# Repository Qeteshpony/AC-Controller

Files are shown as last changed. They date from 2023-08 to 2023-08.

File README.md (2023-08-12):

# Qeteshs AC-Controller



3D Render

[Hardware Documentation](https://qeteshpony.github.io/AC-Controller)

Simple controller for IoT devices with ESP-Home and Home Assistant in mind. This project was mainly started to get better control for our AC system but I guess it can be adapted for about anything. 

The system is based on an ESP32 module, a small LCD and two rotary encoders with optional support for charging and using a LiPo battery. 

The hardware was designed for production by JLCPCB and as many parts as possible were selected from their basic parts library to keep costs low. 

The PCB has two positions for a USB-C port, both are wired in parallel so only one should be soldered in - which one depends on the usecase. 

The display I use is the `DEM 16226 SYH-LY` which is smaller than most 16x2 character displays and available from several retailers. The board most likely needs major changes to be used with another display since the connector is in a different position to most.

I also got shorter 2.54mm headers that only raise the display by about 8mm from the main board so everything is more compact.

The battery used is a 2500 mAH LiPo cell called `LP-785060` with built in protection circuit and about the same measurements as the board so it fits neatly underneath it.

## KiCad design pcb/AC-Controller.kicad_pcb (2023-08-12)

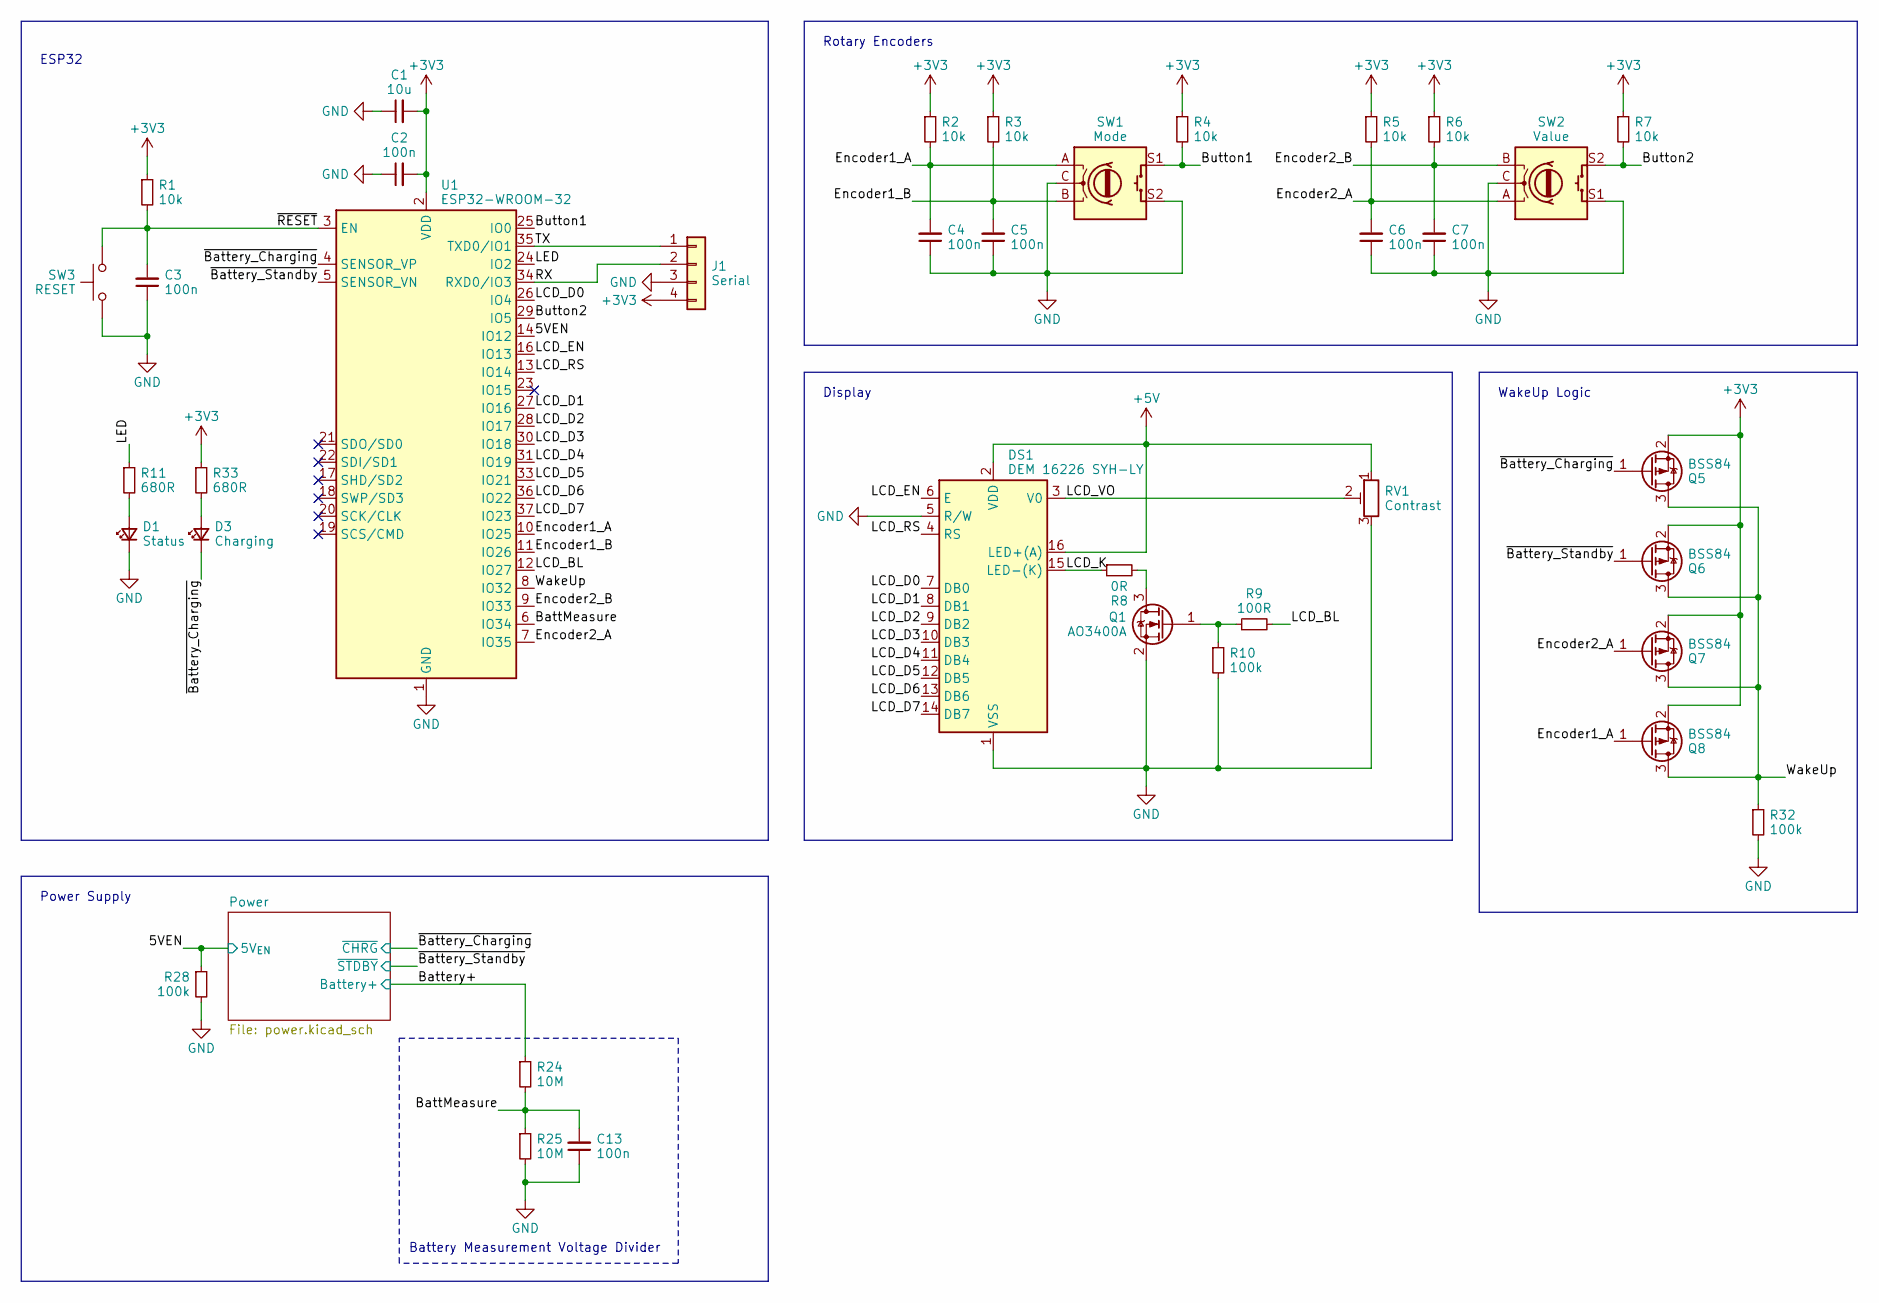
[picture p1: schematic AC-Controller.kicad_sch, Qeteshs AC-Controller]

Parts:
C1: 10u; C_0402_1005Metric; LCSC C15525
C2, C3, C4, C5, C6, C7, C13: 100n; C_0402_1005Metric; LCSC C1525
D1: Status; LED_0603_1608Metric; LCSC C2286
D3: Charging; LED_0603_1608Metric; LCSC C2286
DS1: DEM 16226 SYH-LY
J1: Serial; PinSocket_1x04_P2.54mm_Vertical
Q1: AO3400A; SOT-23; LCSC C20917
Q5, Q6, Q7, Q8: BSS84; SOT-23; LCSC C8492
R1, R2, R3, R4, R5, R6, R7: 10k; R_0402_1005Metric; LCSC C25744
R8: 0R; R_0603_1608Metric_Pad0.98x0.95mm_HandSolder; LCSC C21189
R9: 100R; R_0402_1005Metric; LCSC C25076
R10, R28, R32: 100k; R_0402_1005Metric; LCSC C25741
R11, R33: 680R; R_0402_1005Metric; LCSC C25130
R24, R25: 10M; R_0402_1005Metric; LCSC C26082
RV1: Contrast; Potentiometer_Runtron_RM-065_Vertical
SW1: Mode; RotaryEncoder_Alps_EC12E-Switch_Vertical_H20mm
SW2: Value; RotaryEncoder_Alps_EC12E-Switch_Vertical_H20mm
SW3: RESET; SW_Push_1P1T_XKB_TS-1187A; LCSC C318884
U1: ESP32-WROOM-32; LCSC C82899

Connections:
+3V3: C1.2, C2.2, J1.4, Q5.2 (S), Q6.2 (S), Q7.2 (S), Q8.2 (S), R1.1, R2.1, R3.1, R4.1, R5.1, R6.1, R7.1, R33.1, U1.2 (VDD); also elsewhere on the board
+5V: DS1.2 (VDD), DS1.16 (LED+(A)), RV1.1; also elsewhere on the board
/5VEN: R28.1, U1.14 (IO12); also elsewhere on the board
/BattMeasure: C13.2, R24.2, R25.1, U1.6 (IO34)
/Battery+: R24.1; also elsewhere on the board
/Button1: R4.2, SW1.S1, U1.25 (IO0)
/Button2: R7.2, SW2.S2, U1.29 (IO5)
/Encoder1_A: C4.2, Q8.1 (G), R2.2, SW1.A, U1.10 (IO25)
/Encoder1_B: C5.2, R3.2, SW1.B, U1.11 (IO26)
/Encoder2_A: C6.2, Q7.1 (G), R5.2, SW2.A, U1.7 (IO35)
/Encoder2_B: C7.2, R6.2, SW2.B, U1.9 (IO33)
/LCD_BL: R9.2, U1.12 (IO27)
/LCD_D0: DS1.7 (DB0), U1.26 (IO4)
/LCD_D1: DS1.8 (DB1), U1.27 (IO16)
/LCD_D2: DS1.9 (DB2), U1.28 (IO17)
/LCD_D3: DS1.10 (DB3), U1.30 (IO18)
/LCD_D4: DS1.11 (DB4), U1.31 (IO19)
/LCD_D5: DS1.12 (DB5), U1.33 (IO21)
/LCD_D6: DS1.13 (DB6), U1.36 (IO22)
/LCD_D7: DS1.14 (DB7), U1.37 (IO23)
/LCD_EN: DS1.6 (E), U1.16 (IO13)
/LCD_K: DS1.15 (LED-(K)), R8.1
/LCD_RS: DS1.4 (RS), U1.13 (IO14)
/LCD_VO: DS1.3 (V0), RV1.2
/LED: R11.1, U1.24 (IO2)
/RX: J1.2, U1.34 (RXD0/IO3)
/TX: J1.1, U1.35 (TXD0/IO1)
/WakeUp: Q5.3 (D), Q6.3 (D), Q7.3 (D), Q8.3 (D), R32.1, U1.8 (IO32)
/~Battery_Charging: D3.1 (K), Q5.1 (G), U1.4 (SENSOR_VP); also elsewhere on the board
/~Battery_Standby: Q6.1 (G), U1.5 (SENSOR_VN); also elsewhere on the board
/~RESET: C3.2, R1.2, SW3.2, U1.3 (EN)
GND: C1.1, C2.1, C3.1, C4.1, C5.1, C6.1, C7.1, C13.1, D1.1 (K), DS1.1 (VSS), DS1.5 (R/W), J1.3, Q1.2 (S), R10.2, R25.2, R28.2, R32.2, RV1.3, SW1.C, SW1.S2, SW2.C, SW2.S1, SW3.1, U1.1 (GND), U1.15 (GND), U1.38 (GND), U1.39 (GND); also elsewhere on the board
unnamed: D1.2 (A), R11.2
unnamed: D3.2 (A), R33.2
unnamed: Q1.3 (D), R8.2
unnamed: Q1.1 (G), R9.1, R10.1

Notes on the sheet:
Display
WakeUp Logic
ESP32
Battery Measurement Voltage Divider
Power Supply
Rotary Encoders

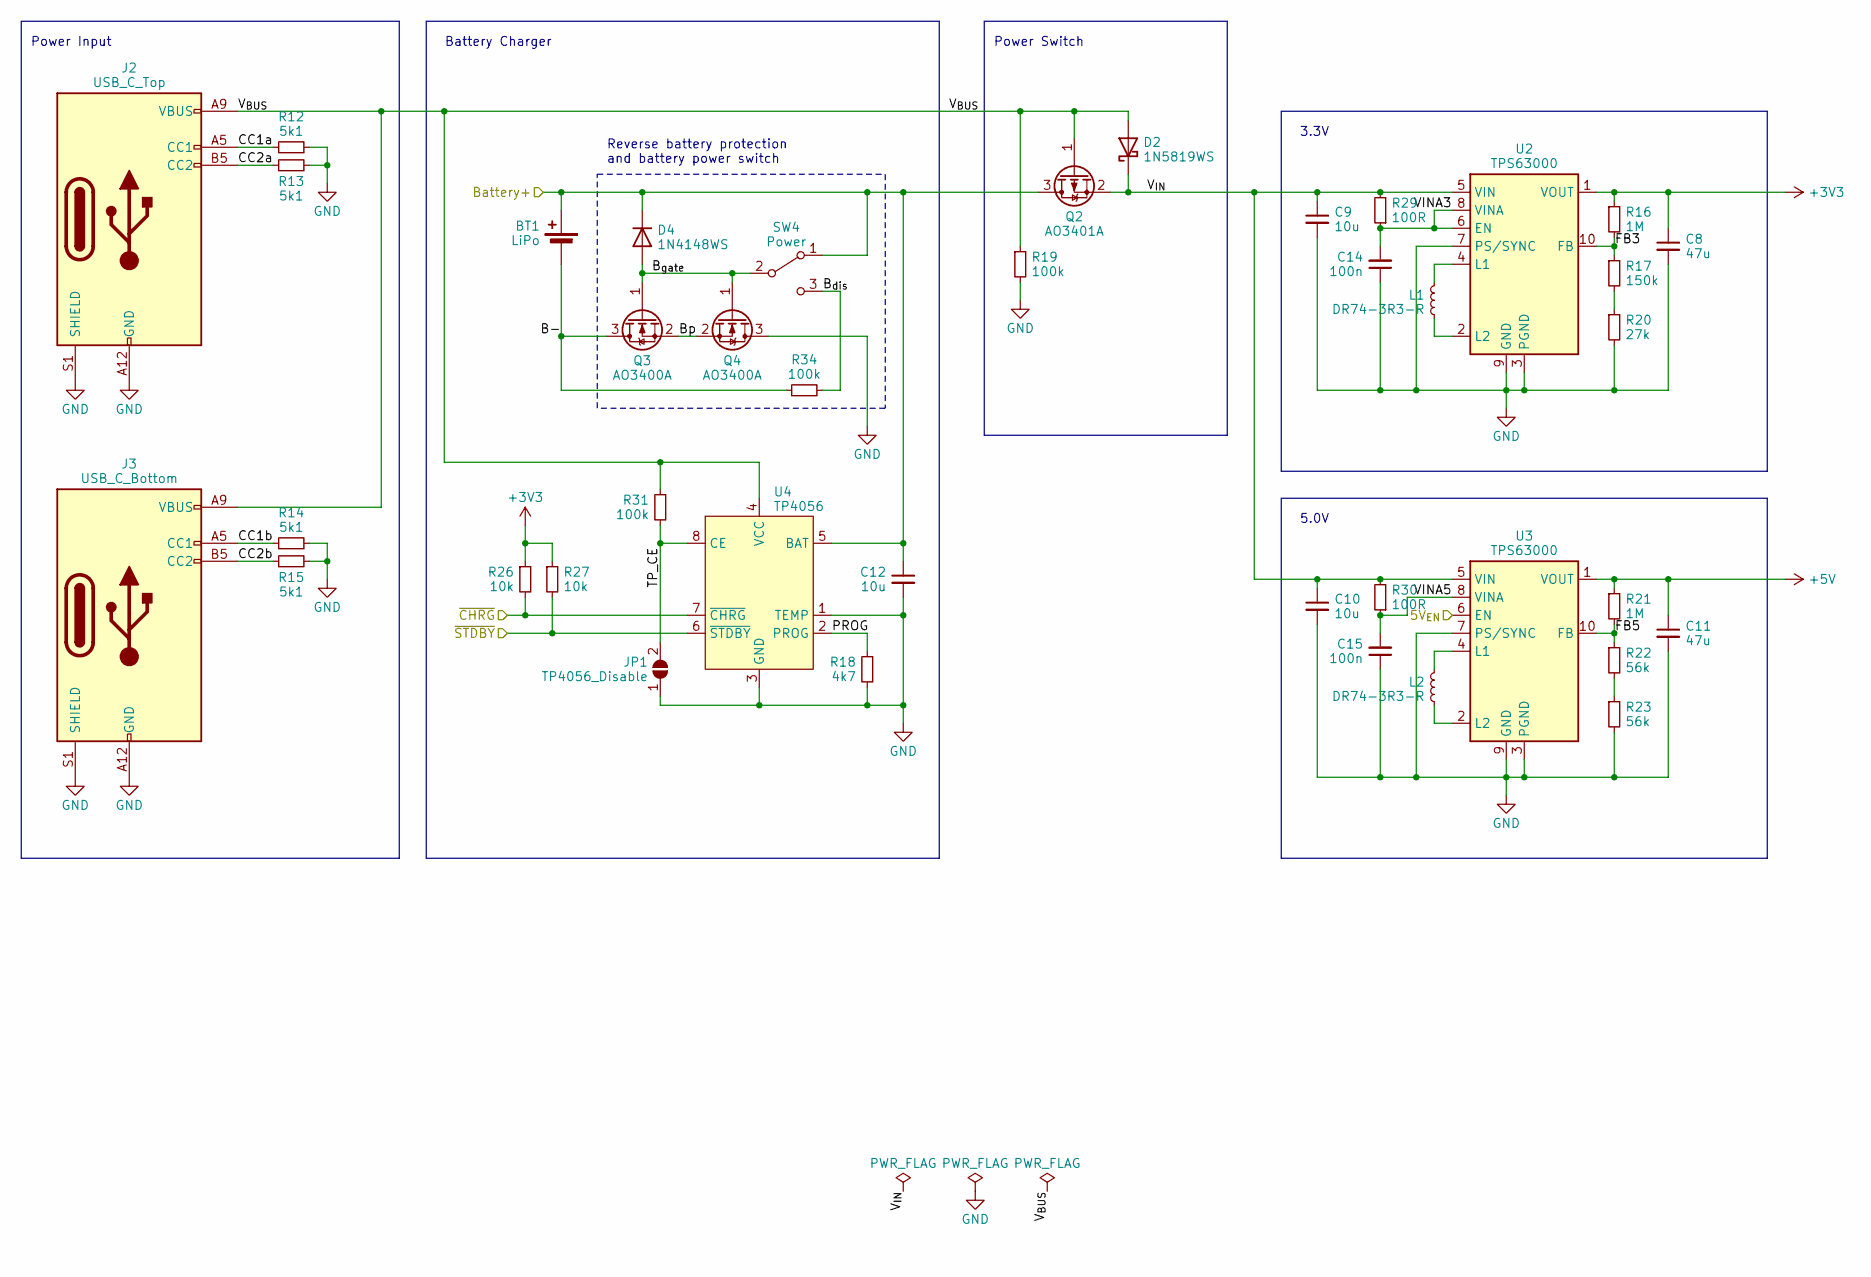
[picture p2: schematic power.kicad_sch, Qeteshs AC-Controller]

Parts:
BT1: LiPo; JST_PH_S2B-PH-K_1x02_P2.00mm_Horizontal
C8, C11: 47u; C_0805_2012Metric; LCSC C16780
C9, C10, C12: 10u; C_0603_1608Metric; LCSC C96446
C14, C15: 100n; C_0402_1005Metric; LCSC C1525
D2: 1N5819WS; D_SOD-323; LCSC C191023
D4: 1N4148WS; D_SOD-323; LCSC C2128
J2: USB_C_Top; GCT_USB4125-GF-A_REVA2; LCSC C283540
J3: USB_C_Bottom; GCT_USB4125-GF-A_REVA2; LCSC C283540
JP1: TP4056_Disable; SolderJumper-2_P1.3mm_Open_RoundedPad1.0x1.5mm
L1, L2: DR74-3R3-R; EATON_DR74
Q2: AO3401A; SOT-23; LCSC C15127
Q3, Q4: AO3400A; SOT-23; LCSC C20917
R12, R13, R14, R15: 5k1; R_0402_1005Metric; LCSC C25905
R16, R21: 1M; R_0402_1005Metric; LCSC C26083
R17: 150k; R_0402_1005Metric; LCSC C25755
R18: 4k7; R_0603_1608Metric_Pad0.98x0.95mm_HandSolder; LCSC C23162
R19, R31, R34: 100k; R_0402_1005Metric; LCSC C25741
R20: 27k; R_0402_1005Metric; LCSC C25771
R22, R23: 56k; R_0402_1005Metric; LCSC C25796
R26, R27: 10k; R_0402_1005Metric; LCSC C25744
R29, R30: 100R; R_0402_1005Metric; LCSC C25076
SW4: Power; SW_SPDT_PCM12; LCSC C221841
U2, U3: TPS63000; Texas_DRC0010J; LCSC C24966
U4: TP4056; SOP127P600X175-9N; LCSC C16581

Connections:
+3V3: C8.1, R16.1, R26.1, R27.1, U2.1 (VOUT); also elsewhere on the board
+5V: C11.1, R21.1, U3.1 (VOUT); also elsewhere on the board
/5VEN: U3.6 (EN); also elsewhere on the board
/Battery+: BT1.1 (+), C12.1, D4.1 (K), Q2.3 (D), SW4.1 (A), U4.5 (BAT); also elsewhere on the board
/Power/B-: BT1.2 (-), Q3.3 (D), R34.1
/Power/B_{dis}: R34.2, SW4.3 (C)
/Power/B_{gate}: D4.2 (A), Q3.1 (G), Q4.1 (G), SW4.2 (B)
/Power/Bp: Q3.2 (S), Q4.2 (S)
/Power/CC1a: J2.A5 (CC1), R12.1
/Power/CC1b: J3.A5 (CC1), R14.1
/Power/CC2a: J2.B5 (CC2), R13.1
/Power/CC2b: J3.B5 (CC2), R15.1
/Power/FB3: R16.2, R17.1, U2.10 (FB)
/Power/FB5: R21.2, R22.1, U3.10 (FB)
/Power/PROG: R18.1, U4.2 (PROG)
/Power/TP_CE: JP1.2 (B), R31.2, U4.8 (CE)
/Power/VINA3: C14.2, R29.1, U2.6 (EN), U2.8 (VINA)
/Power/VINA5: C15.2, R30.1, U3.8 (VINA)
/Power/V_{BUS}: D2.2 (A), J2.A9 (VBUS), J2.B9 (VBUS), J3.A9 (VBUS), J3.B9 (VBUS), Q2.1 (G), R19.1, R31.1, U4.4 (VCC)
/Power/V_{IN}: C9.1, C10.1, D2.1 (K), Q2.2 (S), R29.2, R30.2, U2.5 (VIN), U3.5 (VIN)
/~Battery_Charging: R26.2, U4.7 (~CHRG); also elsewhere on the board
/~Battery_Standby: R27.2, U4.6 (~STDBY); also elsewhere on the board
GND: C8.2, C9.2, C10.2, C11.2, C12.2, C14.1, C15.1, J2.A12 (GND), J2.B12 (GND), J2.S1 (SHIELD), J3.A12 (GND), J3.B12 (GND), J3.S1 (SHIELD), JP1.1 (A), Q4.3 (D), R12.2, R13.2, R14.2, R15.2, R18.2, R19.2, R20.2, R23.2, U2.3 (PGND), U2.7 (PS/SYNC), U2.9 (GND), U2.11 (PGND), U3.3 (PGND), U3.7 (PS/SYNC), U3.9 (GND), U3.11 (PGND), U4.1 (TEMP), U4.3 (GND), U4.9 (EP); also elsewhere on the board
unnamed: R17.2, R20.1
unnamed: R22.2, R23.1
unnamed: L1.2, U2.4 (L1)
unnamed: L1.1, U2.2 (L2)
unnamed: L2.2, U3.4 (L1)
unnamed: L2.1, U3.2 (L2)

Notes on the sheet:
Power Input
Power Switch
3.3V
Battery Charger
5.0V
Reverse battery protection and battery power switch

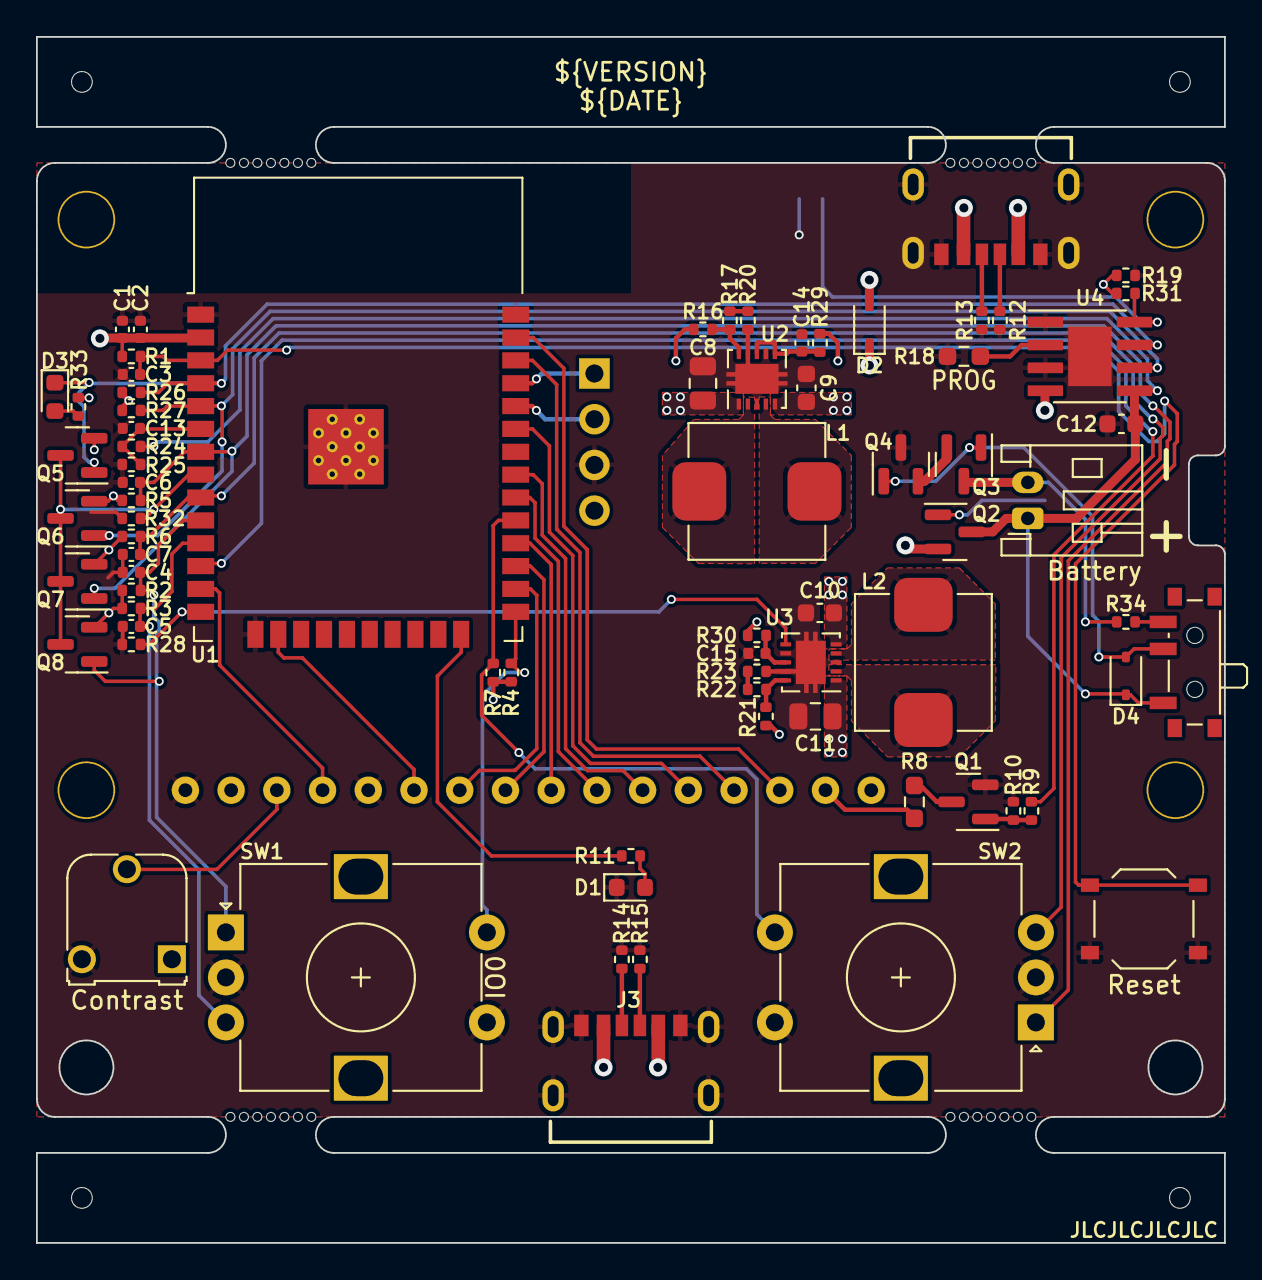
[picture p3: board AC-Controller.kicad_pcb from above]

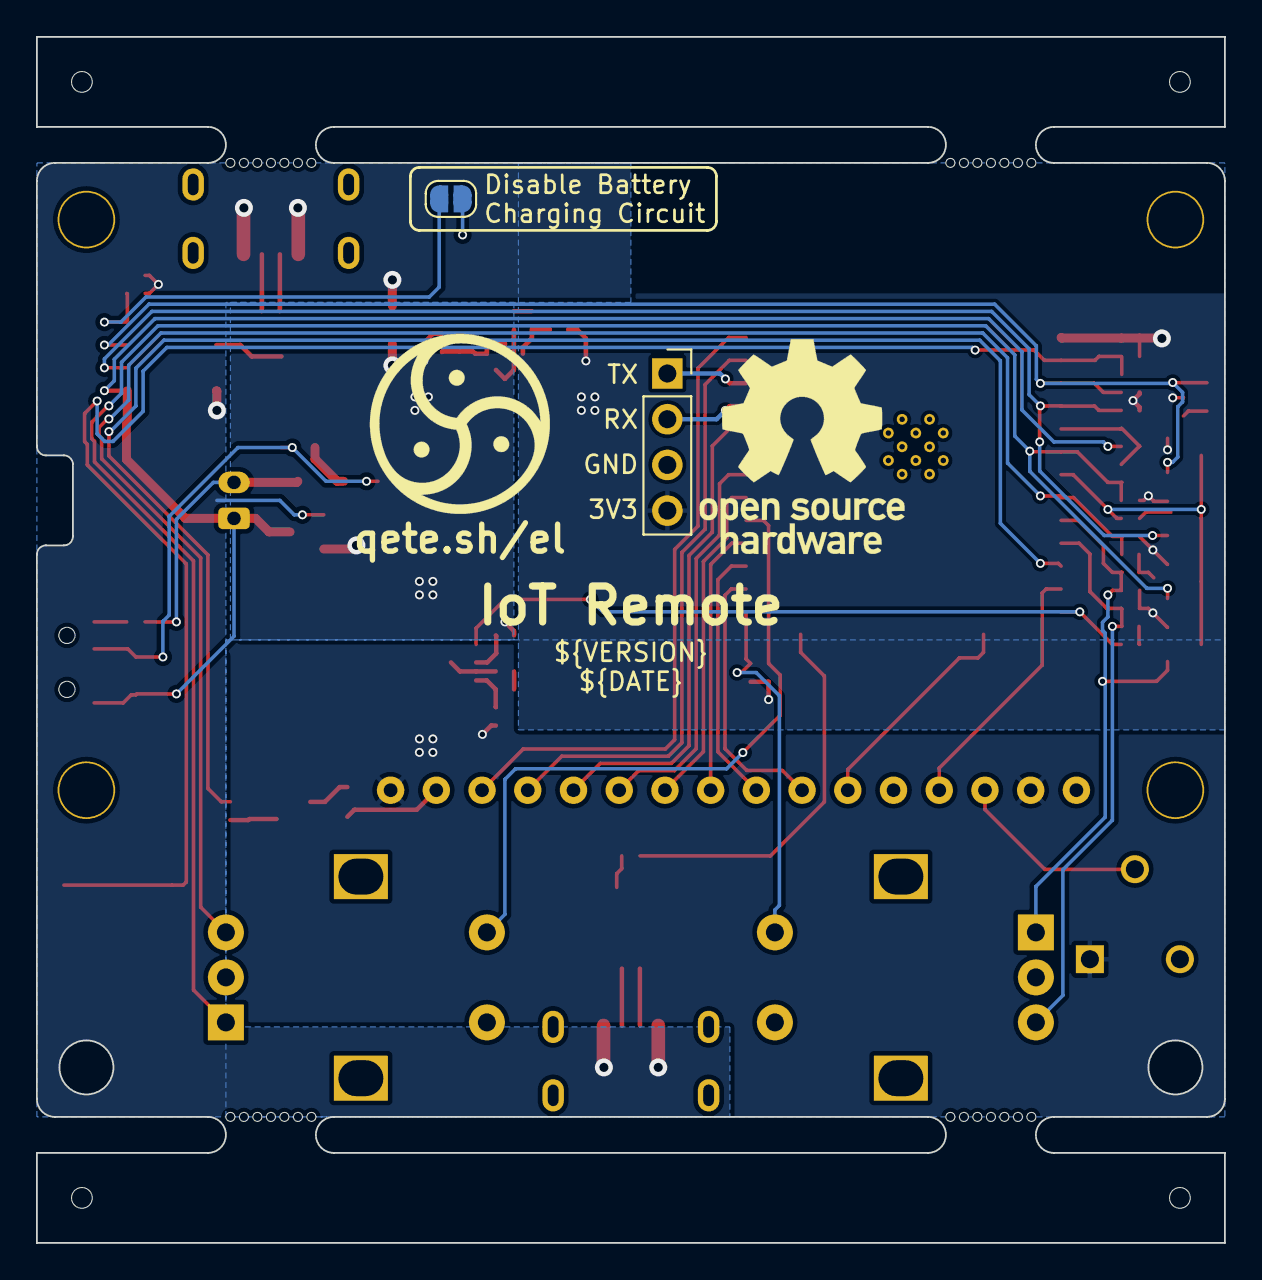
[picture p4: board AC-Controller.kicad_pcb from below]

Board: 2 copper layers, 66.0 x 67.0 mm, 82 parts (2 on the bottom side), 58 nets.

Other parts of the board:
mouse-bite-2mm-slot, mouse-bite-2mm-slot#2, mouse-bite-2mm-slot#3, mouse-bite-2mm-slot#4: VAL**; mouse-bite-2x5mm-slot-onesided-v2

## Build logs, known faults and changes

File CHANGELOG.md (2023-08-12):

# Changelog

## [1.1.0](https://github.com/Qeteshpony/AC-Controller/compare/v1.0.0...v1.1.0) (2023-08-12)

### Features

* add charging indicator LED ([d885e59](https://github.com/Qeteshpony/AC-Controller/commit/d885e595ab1d06b7fe9d112825ddc37f4f6a76c9))
* add cutout for battery cable ([333c9cb](https://github.com/Qeteshpony/AC-Controller/commit/333c9cb049eb8d4ab6ad8abca67b8dd680415c41))
* add disable jumper for battery charger ([5c41dfc](https://github.com/Qeteshpony/AC-Controller/commit/5c41dfcbae3ee2b01b34da61ba77e1b2df63206b))
* add more ways to wake up ([73e31f4](https://github.com/Qeteshpony/AC-Controller/commit/73e31f4d093f652f1cdb53bde135fe8d08e76870))
* add power switch ([cbf0ec8](https://github.com/Qeteshpony/AC-Controller/commit/cbf0ec8e941afb3ebb258f95848fcb0a09bf4a45))
* add Reset button ([44b38c6](https://github.com/Qeteshpony/AC-Controller/commit/44b38c6d1f62f4290a322de3b95969dab85d92b4))
* remove battery protection IC ([c65e03b](https://github.com/Qeteshpony/AC-Controller/commit/c65e03bea2603eabd93ade0f0a7cbaea6a642238))
* replace contrast pot with more common type ([c555595](https://github.com/Qeteshpony/AC-Controller/commit/c55559549f2424a5b88c57892c225df1892b805b))
* replace TP4056 Prog Resistor footprint with 0603 ([2b51514](https://github.com/Qeteshpony/AC-Controller/commit/2b515149b5ace57cb8239b1a31a398b86d224ad6))

### Bug Fixes

* add missing part numbers ([94f4ee7](https://github.com/Qeteshpony/AC-Controller/commit/94f4ee77e1d125d8f63c7ecfd9b0cbab44991521))
* turn around battery connector ([a7d10ba](https://github.com/Qeteshpony/AC-Controller/commit/a7d10ba04260a25a6ee9b8469a8d19d0e306c8d7))

## 1.0.0 (2023-07-21)

### Features

* add battery protection ([bacf1b3](https://github.com/Qeteshpony/AC-Controller/commit/bacf1b3847ffae33973738c76fd87cd7fe99a982))
* add reverse polarity protection for battery input ([e4d883d](https://github.com/Qeteshpony/AC-Controller/commit/e4d883dde2a0d5db8c5e74c48428e906f7912c86))
* initial commit ([7581de3](https://github.com/Qeteshpony/AC-Controller/commit/7581de320ac0e4daabf59f4a8b7881be41da7255))

### Bug Fixes

* add missing JLC part numbers ([2dcdca6](https://github.com/Qeteshpony/AC-Controller/commit/2dcdca6cb2afa226be83c4eeac61c9e839ad276b))

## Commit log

2023-06-29 feat: initial commit
    [AC-Controller.kicad_pcb, AC-Controller.kicad_sch, power.kicad_sch]
2023-06-30 style: schematics cleanup
    [AC-Controller.kicad_pcb, AC-Controller.kicad_sch, power.kicad_sch]
2023-06-30 style: use correct variables
    [AC-Controller.kicad_pcb, AC-Controller.kicad_sch, power.kicad_sch]
2023-06-30 style: add 3d models for pcb render
    [AC-Controller.kicad_pcb, power.kicad_sch]
2023-07-16 feat: add battery protection
    [AC-Controller.kicad_pcb, AC-Controller.kicad_sch, power.kicad_sch]
2023-07-17 feat: add reverse polarity protection for battery input
    just to make sure a reverse connected battery won't kill the circuit
    [AC-Controller.kicad_pcb, AC-Controller.kicad_sch, power.kicad_sch]
2023-07-21 fix: add missing JLC part numbers
    [AC-Controller.kicad_pcb, AC-Controller.kicad_sch, power.kicad_sch]
2023-08-03 feat: add Reset button
    [AC-Controller.kicad_pcb, AC-Controller.kicad_sch]
2023-08-03 fix: turn around battery connector
    Battery connector was not reachable with display installed
    [AC-Controller.kicad_pcb]
2023-08-05 feat: remove battery protection IC
    Since I only use protected battery packs (which is highly recommended) the additional protection IC on the PCB was obsolete and only raised production cost.
    [AC-Controller.kicad_pcb, AC-Controller.kicad_sch, power.kicad_sch]
2023-08-05 feat: add charging indicator LED
    [AC-Controller.kicad_pcb, AC-Controller.kicad_sch]
2023-08-05 feat: replace contrast pot with more common type
    [AC-Controller.kicad_pcb, AC-Controller.kicad_sch]
2023-08-05 feat: replace TP4056 Prog Resistor footprint with 0603
    Replace the footprint for the programming resistor to 0603 to make replacing it easier. Also changing the default value to 4.7k for slower charge and less heat production
    [AC-Controller.kicad_pcb, AC-Controller.kicad_sch, power.kicad_sch]
2023-08-05 feat: add cutout for battery cable
    [AC-Controller.kicad_pcb, power.kicad_sch]
2023-08-06 feat: add disable jumper for battery charger
    Adding a jumper to disable the TP4056 Battery Charger IC in case no battery is connected and the device is powered by USB only. No need for the IC to draw power in that case.
    [AC-Controller.kicad_pcb, AC-Controller.kicad_sch, power.kicad_sch]
2023-08-06 docs: add info about display and battery
2023-08-06 style: board and schematics cleanup
    [AC-Controller.kicad_pcb, AC-Controller.kicad_sch]
2023-08-07 feat: add more ways to wake up
    Adding simple MOSFET logic to watch 4 signals for waking up from deep sleep
    [AC-Controller.kicad_pcb, AC-Controller.kicad_sch, power.kicad_sch]
2023-08-08 feat: add power switch
    Add switch to disconnect battery power from the circuit for when the device is not in use for a long time and reduce power consumption to a few nA
    [AC-Controller.kicad_pcb, power.kicad_sch]
2023-08-10 style: cleanup
    [AC-Controller.kicad_pcb, AC-Controller.kicad_sch, power.kicad_sch]
2023-08-12 fix: add missing part numbers
    [AC-Controller.kicad_pcb, AC-Controller.kicad_sch, power.kicad_sch]
